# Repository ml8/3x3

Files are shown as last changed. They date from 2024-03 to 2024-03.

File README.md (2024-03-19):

# 3x3 Macropad: PCB, Firmware, STL, Programmer

Self-designed, hacked-together 3x3 macropad.

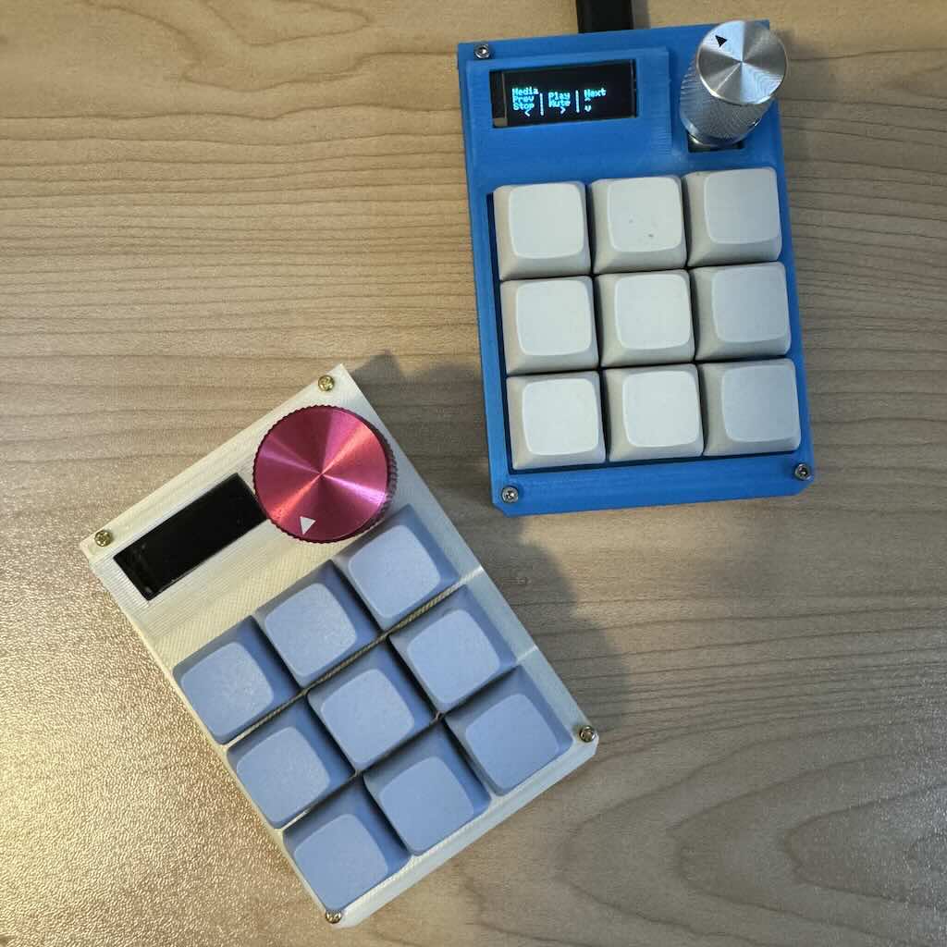
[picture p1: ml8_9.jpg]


## Features:

* 4 layers configurable with [via](https://www.caniusevia.com/) and selectable
  by clicking the rotary encoder.
* OLED display to display per-layer text (programmable with tool in
  [`cli/`](cli/README.md)).
* Rotary encoder with volume control and layer select button.
* 256Kb EEPROM (24LC256).

## Project layout:

* [`cli/`](cli/README.md) - Tool to program keyboard (primarily to change OLED
  text) and change the layer text.
* [`via/`](via/README.md) - Via json config (TODO: merge into via) that can be
  used for creating custom keymaps in Via (once merged into via, this should no
  longer be necessary).
* [`firmware/`](firmware/README.md) - [QMK](https://qmk.fm/)-based firmware
  (TODO: merge into QMK) and instructions for flashing the firmware.
* [`hardware/`](hardware/README.md) Gerber file for PCB and STL/3mf for
  enclosure.

## Updating firmware:

In order to flash a new firmware version, the device needs to be reset and
boot into DFU mode for flashing. This can be done in one of two ways:

* Hold down the top left key in the 3x3 grid and plug the keyboard in. The
  keyboard should enter DFU mode for a period of time that will allow you to
  flash new firmware.
* If this does not work, you can use the reset button on top of the PCB. You'll
  need to remove at least the top cover in order to access the button.

See the instructions in [`firmware/`](firmware/) for more details.

## Kit Assembly

Overview and detailed Assembly instructions can be found in the
[`hardware/`](hardware/README.md) directory.

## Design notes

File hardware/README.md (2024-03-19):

# Hardware

This contains the Gerber for the PCB and STL/3mf files for the enclosure.

## BOM

All components are through-hole except for the hot-swap sockets.

| Component | Quantity | Note |
| --- | --- | ---- |
| Arduino Pro Micro | 1 | |
| 0.91" 128x32 OLED | 1 | requires hand-wiring |
| 24LC256 EEPROM | 1 | | 
| 6x6 tactile momentary switch | 1 | 5mm or 4.3mm height |
| EC11 Rotary Encoder (clickable) | 1 | + knob |
| 1N4148 diodes | 10 | |
| MX-style switches | 10 | + keycaps |
| 1k resistor | 1 | |
| MX hotswap sockets | 10 | |
| m2x8 screws | 4 | for enclosure |
| m2x4 screws | 4 | for enclosure |
| m2 5mm standoffs | 4 | for enclosure |
| m2 nuts | 4 | for enclosure |

## Assembly Notes

The following is an overview of assembling the macropad. __You can find more
detailed instructions [here](./assembly_detailed.md).__

1. Begin by mounting 3x3 matrix diodes (D1-D9) and hotswap sockets to underside
   of board (where their labels are). Solder these in place.
   * The hotswap sockets are easiest to solder when you put a small amount of
     solder on the pad, then place the socket and heat the pad. 
   * The D10 diode will be soldered on top of the board. 
   * It's easier to solder the hotswap sockets first, so that you don't have to
     worry about the board sitting stably while soldering these.
2. Next, mount the D10 diode, the resistor (R-RESET) to top of board. Solder in
   place.
3. Mount the EEPROM, reset switch, and rotary encoder on top of the board; solder
   them in place.
4. Solder headers facing __upward__ on Pro Micro, then mount to bottom of
   PCB (see completed picture).
5. Use wires to connect sda/scl/vcc/gnd to the corresponding pins on the 128x32
   OLED. The OLED will be mounted to the inside of the enclosure, so make sure
   the wires are long enough to reach, but short enough to fit under the OLED
   once it is mounted.
6. Assemble the bottom of the enclosure, mounting the PCB to the standoffs.
    * Put the nuts in the bottom of the case (you may have to push hard to push
      them in--they should be snug).
    * Screw in the standoffs, then slide the PCB into the bottom of the
      enclosure.
    * Screw 4 m2x4 screws to mount the PCB inm place.
7. Put the switch plate on (do __not__ screw in place) and mount switches in
   hotswap sockets.
8. Program the firmware, if the pro micro is not pre-programmed. Follow the
   instructions in [`firmware/`](../firmware/README.md).
9. Tape or otherwise affix the OLED to the inside of the top of the enclosure,
   then mount the enclosure. Screw it in place with 4 m2x8 screws. Put the
   encoder knob on.

## Assembly Photos

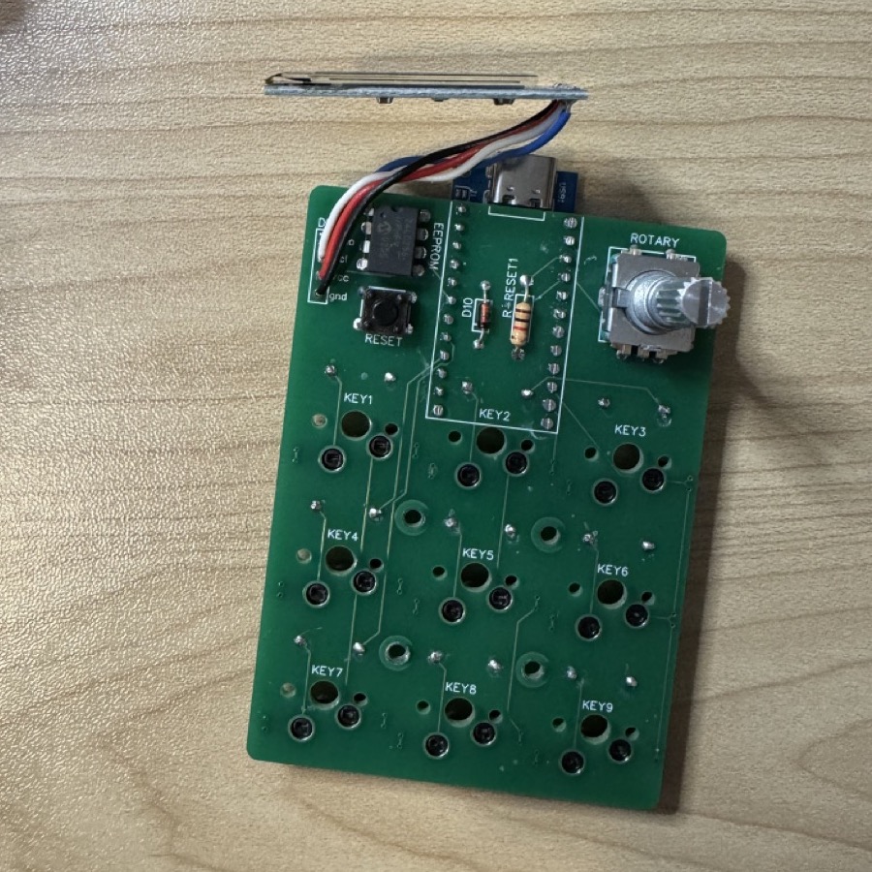
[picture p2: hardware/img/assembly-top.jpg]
top


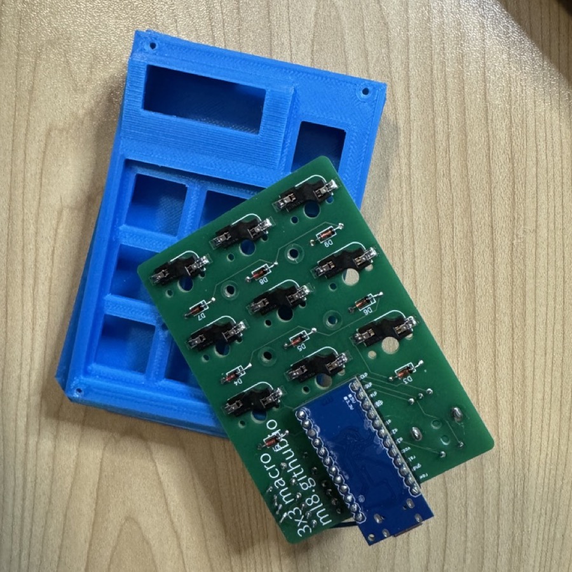
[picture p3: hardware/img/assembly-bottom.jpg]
bottom


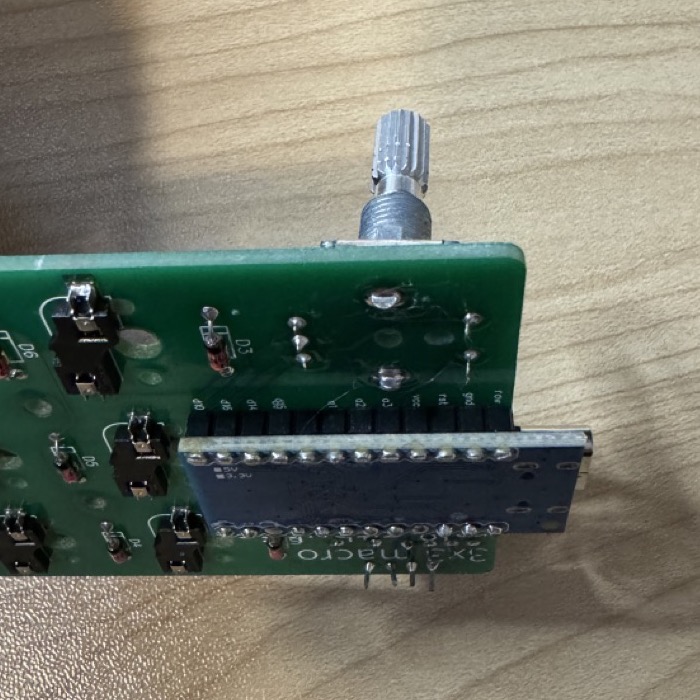
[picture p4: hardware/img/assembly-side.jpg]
side


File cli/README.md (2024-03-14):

# CLI programming tool

Requires golang to be installed.

The programming tool uses device id to distinguish between other QMK keyboards
that may be attached to the same machine. If you only have one QMK keyboard, you
can leave off the device string.

To program layer text:

```
$ go run ./cmd/kbp -device ::6d6c::: -layer [0-3] -text "TEXT"
```

You can use `\\n` for new lines. All text will be written to a single wrapped
line, otherwise.

To reset the layer text:

```
$ go run ./cmd/kbp -device ::6d6c::: -reset
```

Other commands (turning off the OLED, etc.) can be found by using the `-help`
flag.

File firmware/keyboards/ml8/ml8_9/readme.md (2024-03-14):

# ml8/ml8\_9

ml8/ml8\_9

*Firmware for 3x3 macropad with rotary encoder and OLED. Supports via and
reprogramming OLED text via hid programming.*

* Keyboard Maintainer: [Marion Lang](https://github.com/ml8)
* Hardware Supported: [ml8\_9](https://github.com/ml8/3x3)
* Hardware Availability: [open source](https://github.com/ml8/3x3)
* OLED display programmer: [repo](https://github.com/ml8/3x3)

Make example for this keyboard (after setting up your build environment):

    make ml8/ml8_9:default

Flashing example for this keyboard:

    make ml8/ml8_9:default:flash

See the [build environment setup](https://docs.qmk.fm/#/getting_started_build_tools) and the [make instructions](https://docs.qmk.fm/#/getting_started_make_guide) for more information. Brand new to QMK? Start with our [Complete Newbs Guide](https://docs.qmk.fm/#/newbs).

## Bootloader

Enter the bootloader in 3 ways:

* **Bootmagic reset**: Hold down the key at (0,0) in the matrix (top left key in 3x3 matrix) and plug in the keyboard
* **Physical reset button**: Briefly press the button on the top of the PCB
* **Keycode in layout**: Press the key mapped to `QK_BOOT` if it is available

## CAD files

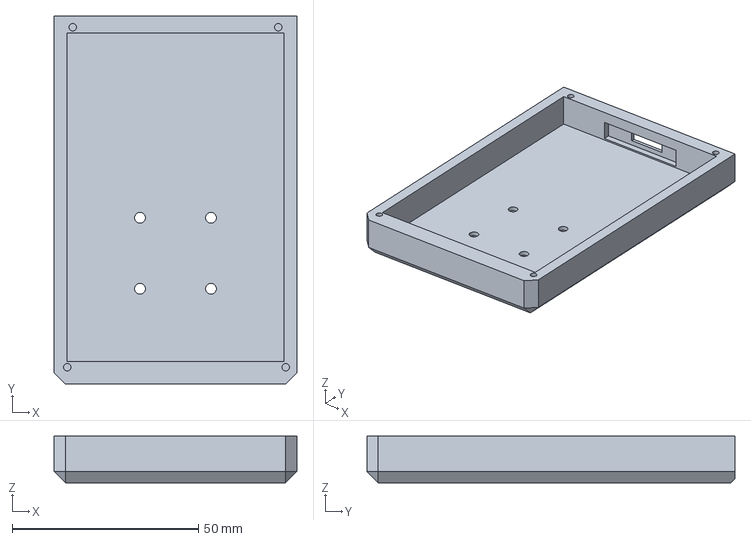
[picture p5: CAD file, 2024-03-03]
hardware/3mf/body.3mf
65.1 x 98.8 x 12.5 mm

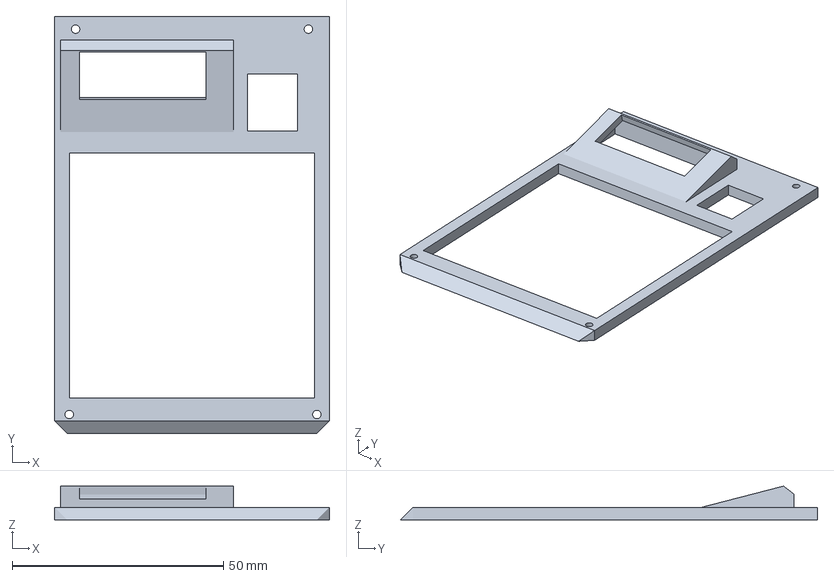
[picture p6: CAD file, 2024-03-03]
hardware/3mf/top.3mf
65.1 x 98.8 x 8.01 mm

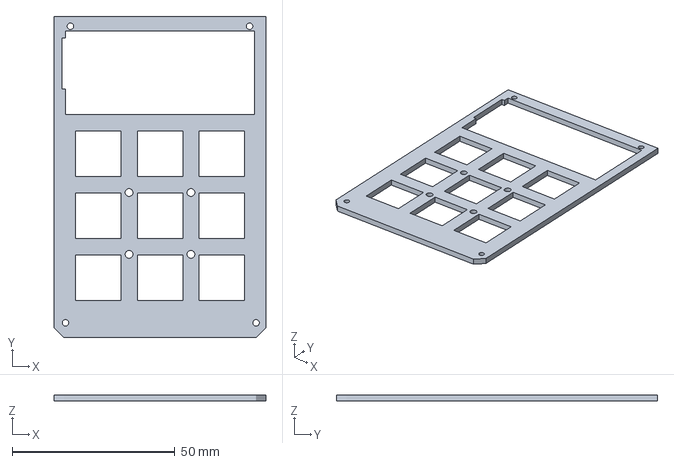
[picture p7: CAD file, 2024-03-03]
hardware/3mf/plate.3mf
65.1 x 98.8 x 2.00 mm

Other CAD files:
hardware/stl/body.stl
hardware/stl/plate.stl
hardware/stl/top.stl

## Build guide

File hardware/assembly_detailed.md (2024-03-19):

# Detailed Assembly Instructions

## Collect materials

Assembling the macropad is relatively straightforward if you have experience
soldering through-hole components. There are a small number of discrete
components. The photo below lays them out.

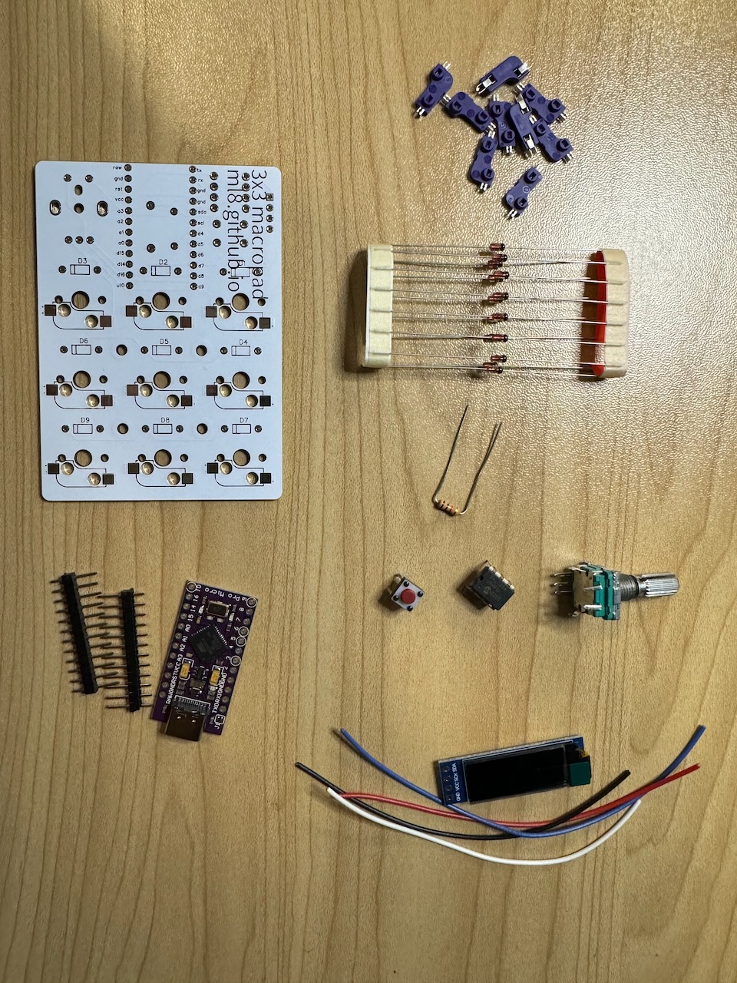
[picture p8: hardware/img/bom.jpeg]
materials


On the left, top to bottom:

* The PCB.
* An Arduino Pro Micro and headers.

On the right, top to bottom (conveniently arranged in the order they'll be
assembled):

* Hot swap switch sockets.
* 1N4148 diodes.
* A 1k ohm resistor.
* Reset/firmware flash button, 24LC256 EEPROM, and rotary encoder.
* 0.91" 128x32 OLED and wires for it.

The rest of these instructions are a suggested order for installing these
components. Note that there is one time when building that a fixed order is
required: __D10 and the resistor__ must be installed before the Arduino.

## Hot swap sockets

The hot swap sockets are the only component that may be unfamiliar to solder if
you are used to through-hole soldering.

Instead of trying to solder the socket tabs directly to the pads they mount on,
it is helpful to first put a blob of solder on the pad.

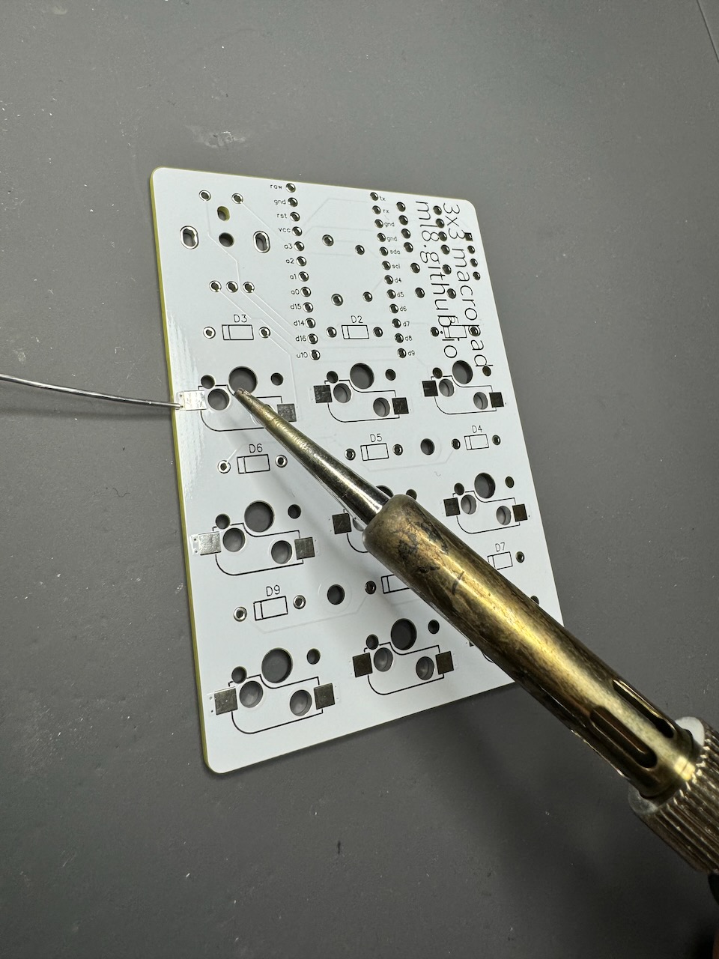
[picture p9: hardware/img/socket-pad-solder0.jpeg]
solder on pad


solder on pads

After putting a bit of solder on each pad, you can now install the sockets.

Pay attention to the orientation of the socket; if the socket is rotated
it will still fit in the holes in the PCB, but it will partially cover the hole
through which the switch stem will need to go.

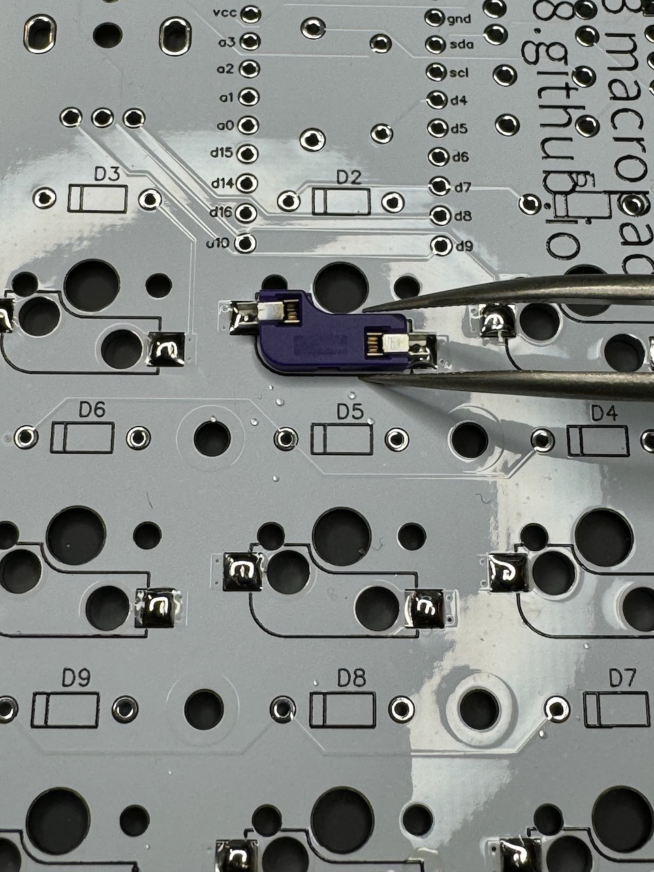
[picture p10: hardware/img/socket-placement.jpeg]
socket placement


To solder the socket to the PCB, place the socket in its location. Then apply
your soldering iron to the socket's tabs. This will melt the solder beneath the
pad after a few seconds and solder the tab to the pad.

You may want to use a pair of tweezers to hold the socket and the tab down while
applying heat.

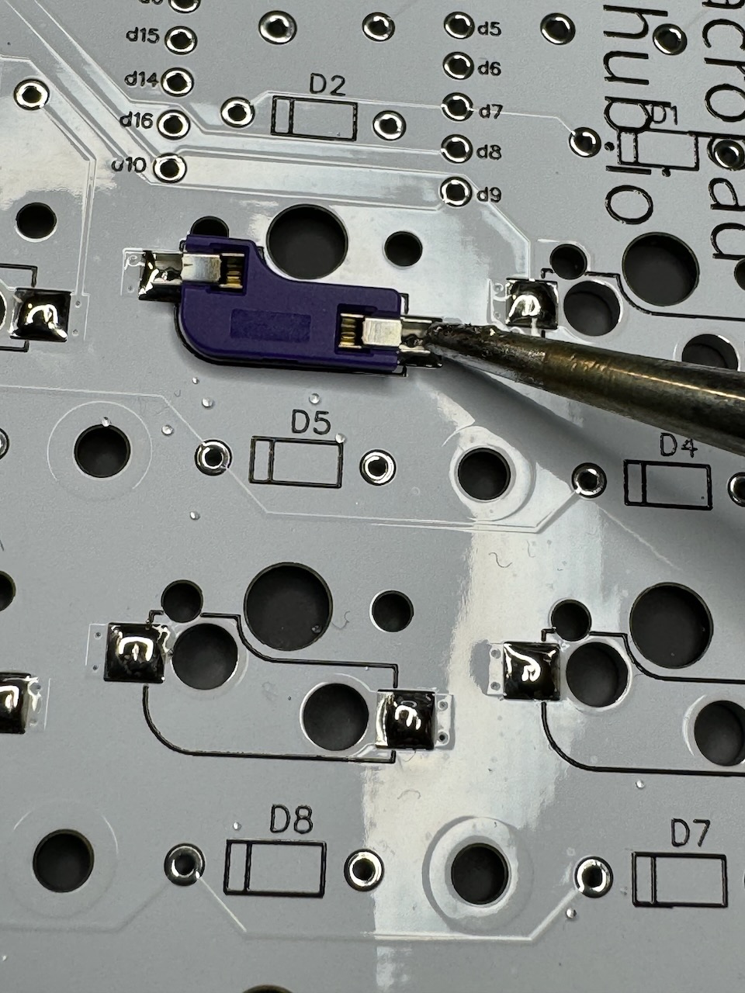
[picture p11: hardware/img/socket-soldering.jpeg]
socket soldering


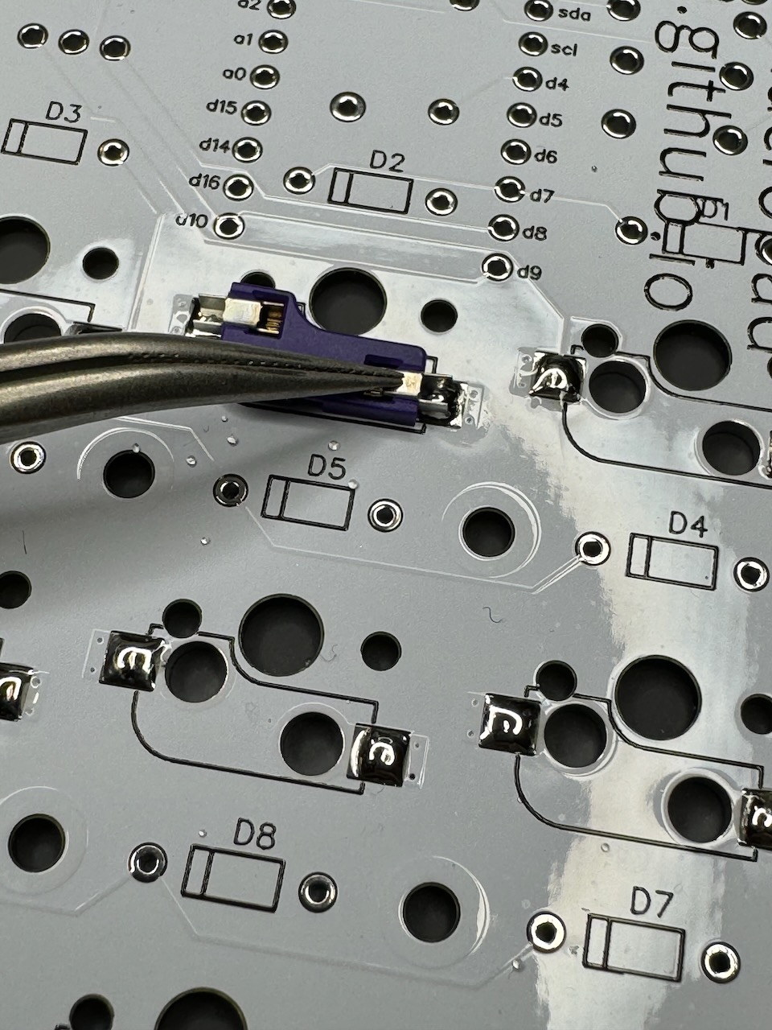
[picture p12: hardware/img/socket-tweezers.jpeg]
hold in place with tweezers


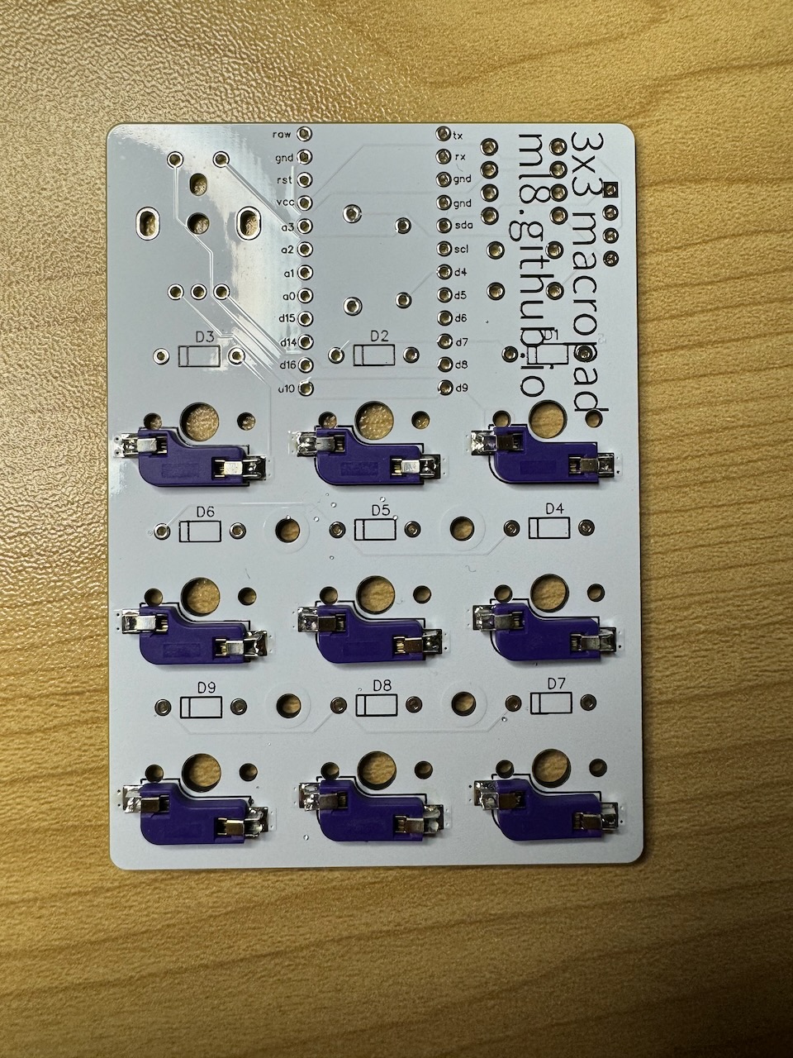
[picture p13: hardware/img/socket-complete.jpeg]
sockets completed


## Diodes 1-9

Now you'll install the diodes. To solder the diode, put the body of the diode on
the bottom of the PCB (the side with the sockets) and the legs through the holes
to the top of the board.

Pay attention to the orientation of the diode -- the orientation matters. The
footprint symbol on the PCB indicates the orientation.

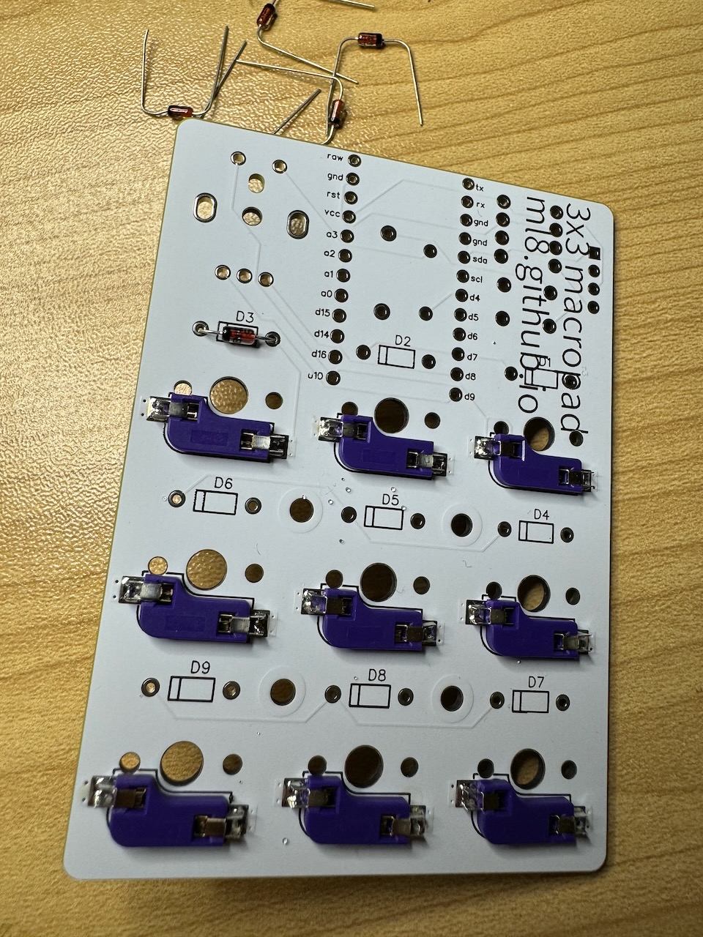
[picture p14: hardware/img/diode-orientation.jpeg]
diode orientation


After putting all the diodes in place, you'll end up with something like this.

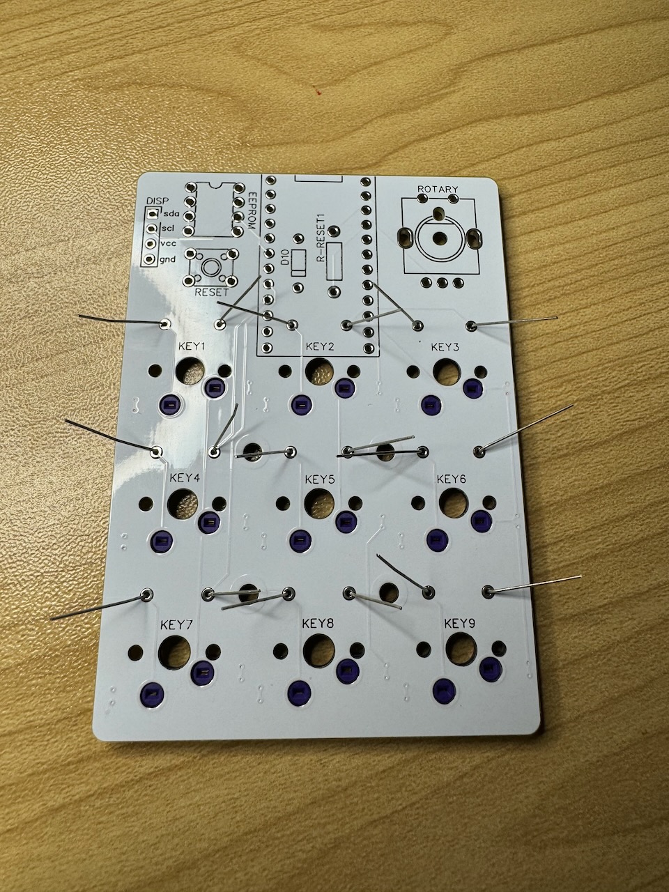
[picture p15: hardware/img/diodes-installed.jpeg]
diodes installed


Solder the legs in place. Cut off the legs when you're done. You should have
something that looks like this:

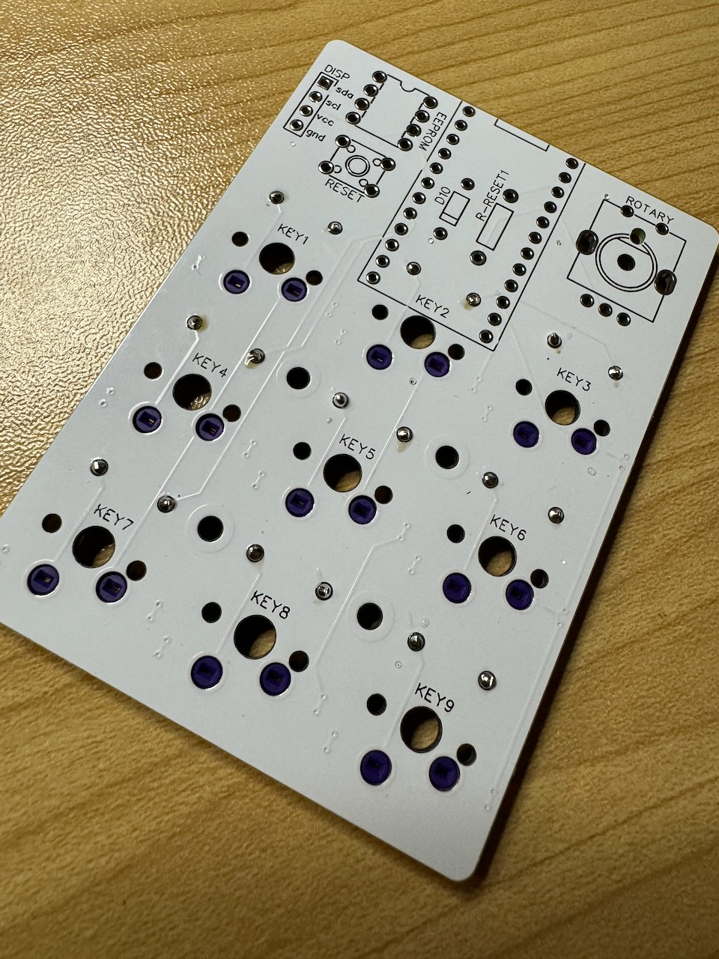
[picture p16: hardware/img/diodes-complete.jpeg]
diodes complete


## Diode 10 and resistor

Diode 10 and the resistor should be placed on top of the board. Their legs will
go through the board and should be soldered from the bottom.

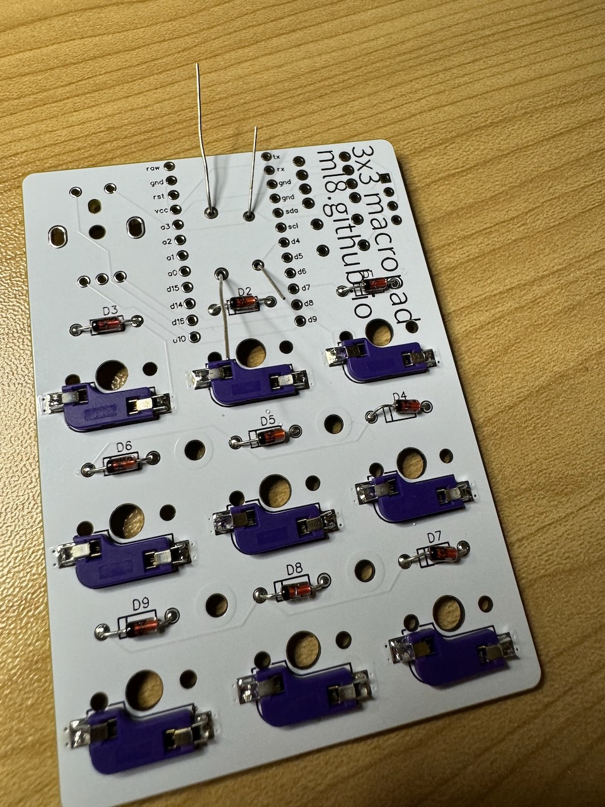
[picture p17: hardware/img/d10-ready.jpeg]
D10 and the resistor ready to solder


When you're complete, the top of the board should look like this.

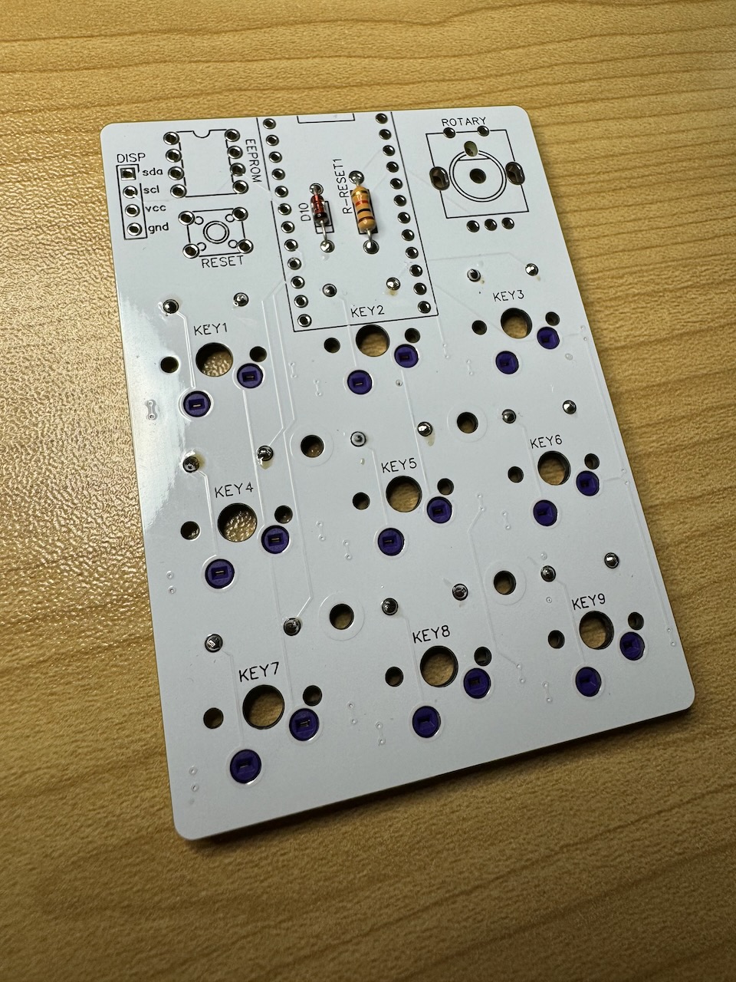
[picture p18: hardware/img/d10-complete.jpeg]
D10 and resistor installed


## EEPROM, reset button, and rotary encoder

Now you can install the EEPROM, reset button, and rotary encoder on the top of
the PCB. All of these components have fixed orientations. The button and the
rotary encoder can only be installed one way, so those should be self-evident.

The EEPROM has a semi-circular notch and dot that indicate the orientation of
the IC and pin 1. Line up the notch with the footprint diagram on the PCB (see
image below).

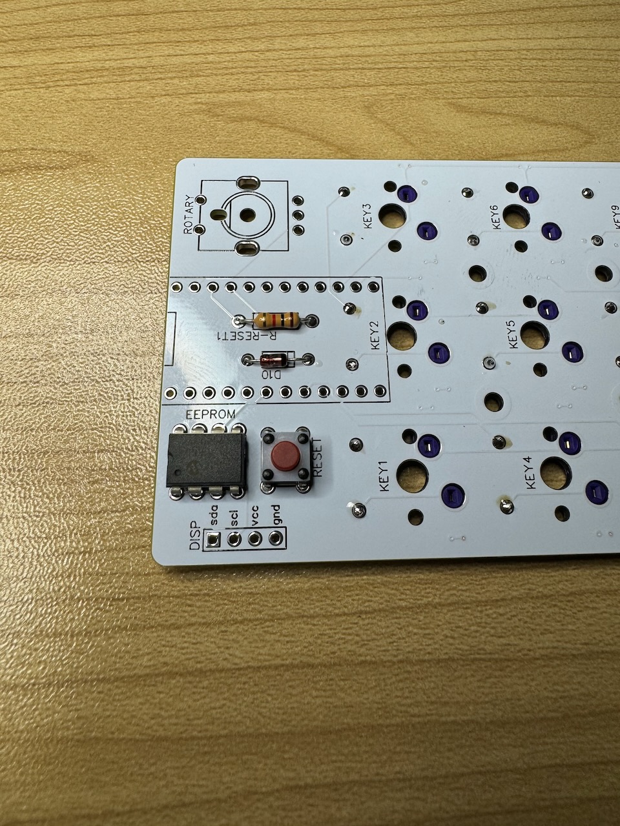
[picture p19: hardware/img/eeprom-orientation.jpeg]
EEPROM orientation


You'll solder each of these components from the bottom. You should install the
EEPROM and the button first, using painters tape or sticky tack to hold them in
place if necessary.

Install the rotary encoder last. Note that you should solder the large tabs on
the side of the encoder, even though they do not carry signal. Soldering these
to the PCB will add stability.

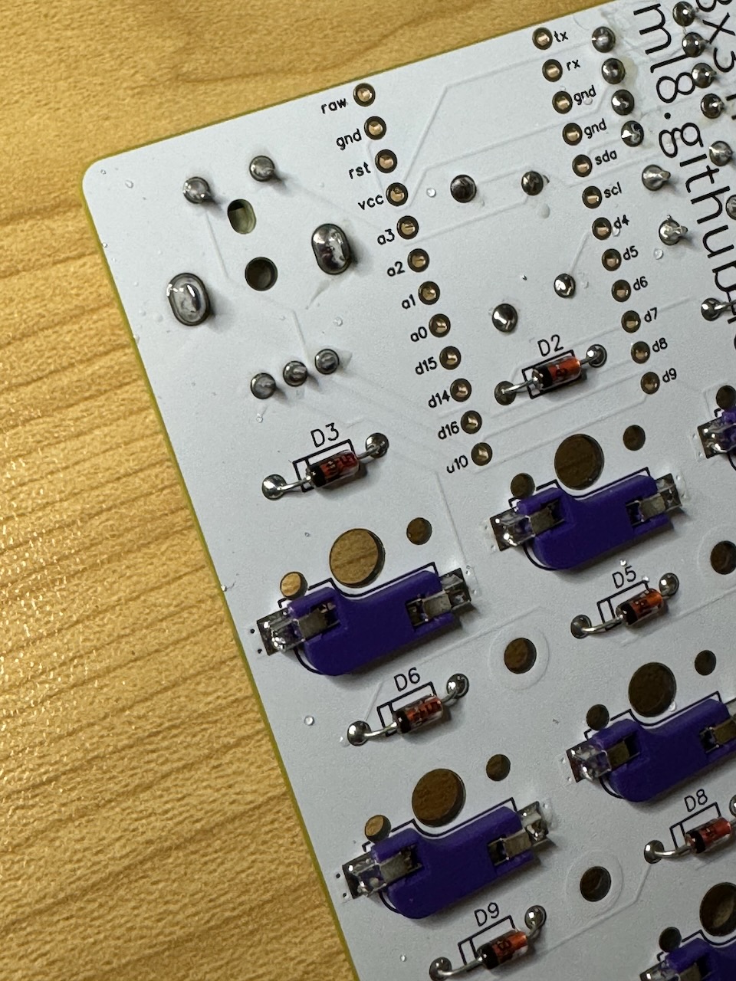
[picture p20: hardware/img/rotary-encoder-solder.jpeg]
rotary encoder tabs


It isn't necessary to trim the legs of any of these components, but it doesn't
hurt anything to do so.

## Arduino

Finally, you'll install the Arduino MCU dev board. This component is installed
kind of oddly (suspended from the bottom of the board). 

First, you'll want to solder the headers to the Ardunio. But __not__ how you
might solder these when using an Arduino on a breadboard. 

You'll want the finished product to look like this (note the long end of the
headers is facing up).

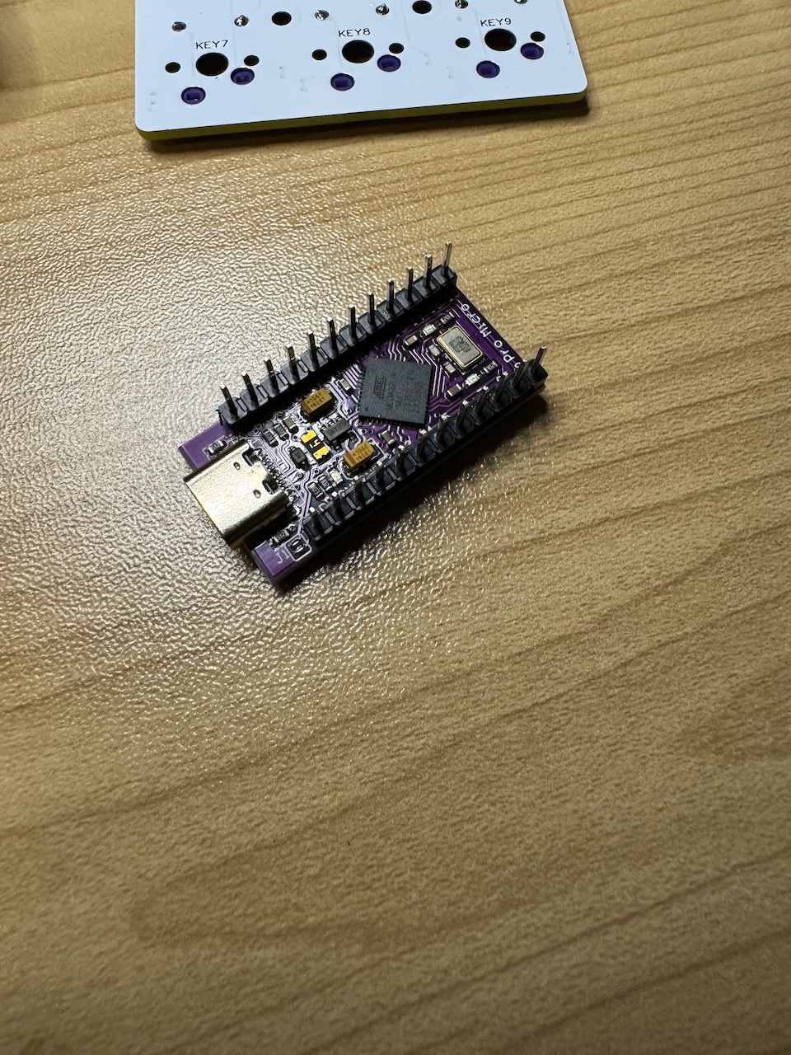
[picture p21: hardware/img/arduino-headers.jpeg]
arduino finished headers


You might find it helpful to do this upside down, with the headers sitting in
their location in the PCB (in order to ensure that they are
straight/perpendicular to both the macropad and the Arduino PCB).

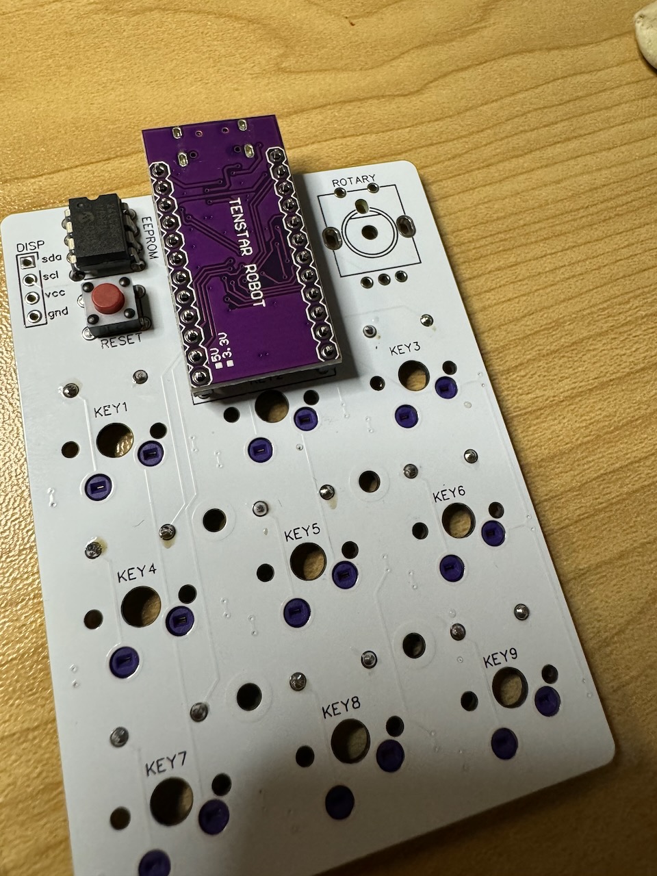
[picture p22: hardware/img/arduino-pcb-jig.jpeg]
arduino pcb as jig


When you are done soldering the headers to the Arduino, install the Arudino on
the bottom of the PCB and solder the headers to the top.

Note that you will need to closely trim the leads on the bottom of the Arduino
and will want to trim the excess header leads on the top of the PCB.

Your finished product should look like this.

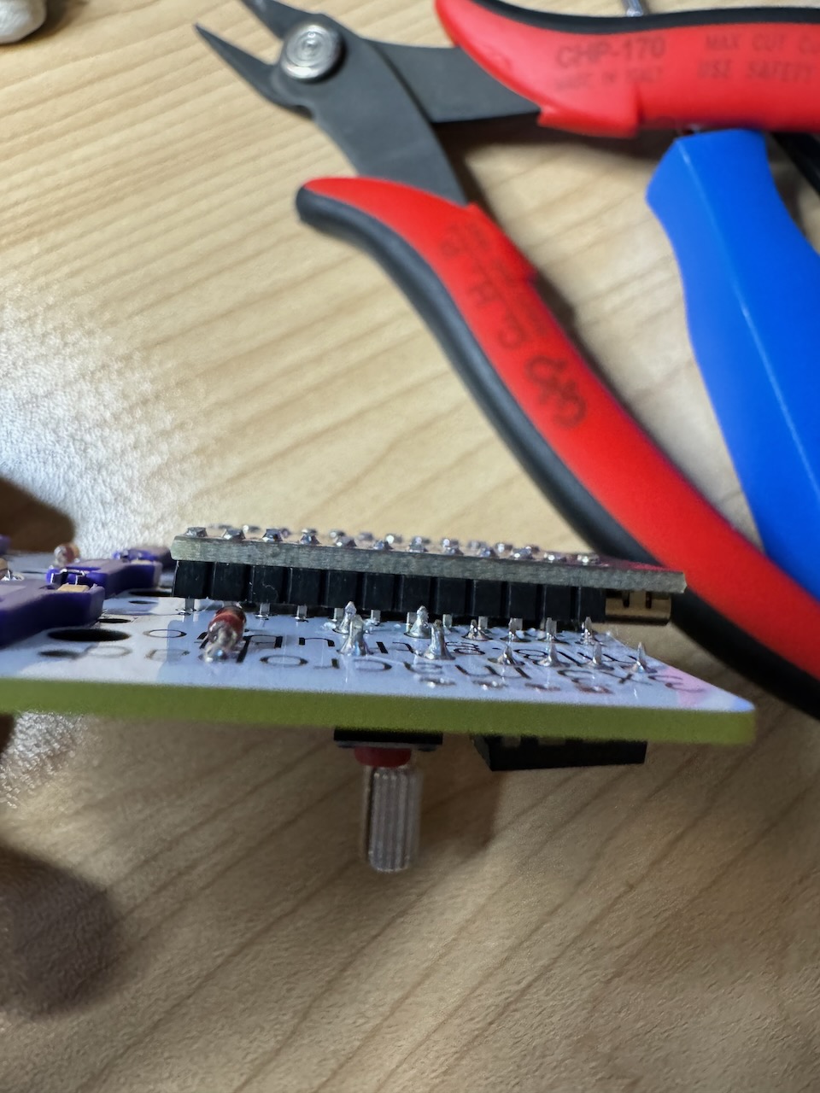
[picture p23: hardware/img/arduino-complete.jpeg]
arduino complete


## OLED

The last component you'll install is the OLED. This is the easiest component to
install, but can be finicky after installing, since you'll need to tape the OLED
to the top of the case. 

For this, you'll just need to solder VCC to VCC, Ground to Ground, and
Clock and Data to Clock and Data. 

Note that I unhelpfully made the orientation of the PCB different from the
orientation of the finished OLED.

You're aiming for this picture.

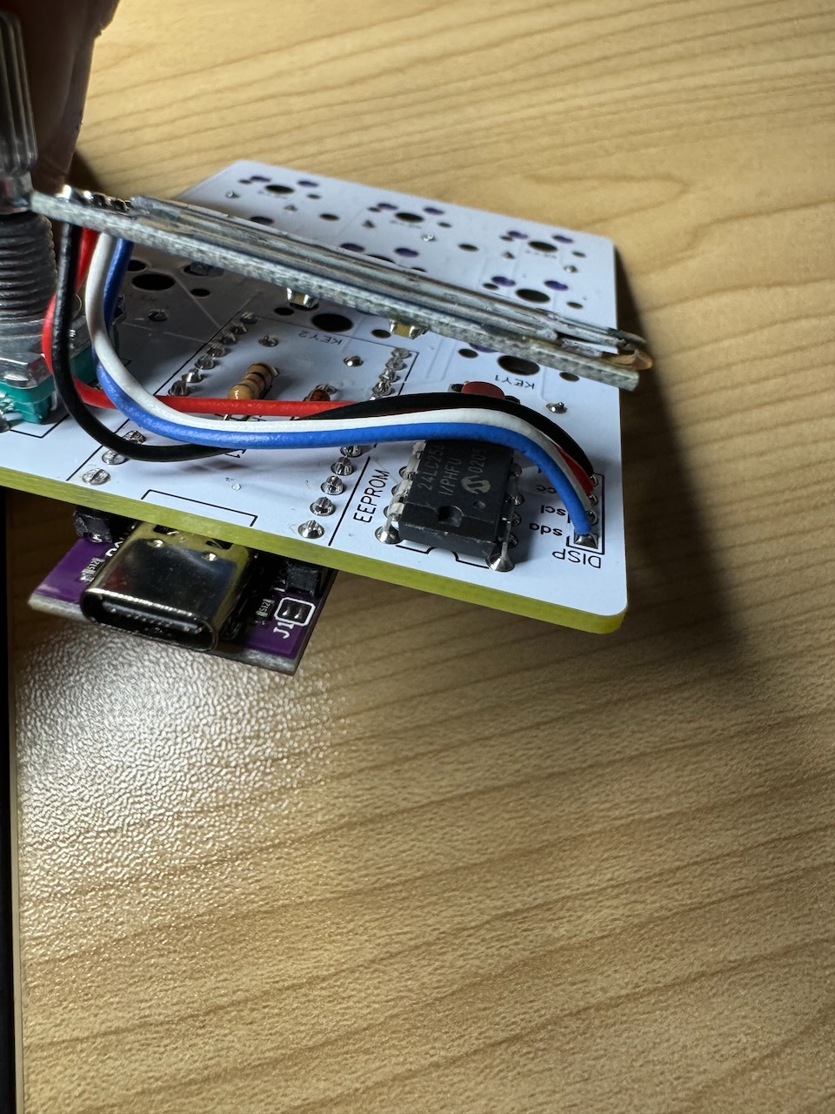
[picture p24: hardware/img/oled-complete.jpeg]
oled complete


## Assembling the case

Now, you'll assemble the case and install your completed PCB in the case.

You'll start by screwing the standoffs into the corresponding nuts. The nuts are
held in place by the cutouts on the bottom of the case. They may be a tight
squeeze. You can use the end of a screwdriver to push hard on the nuts to seat
them.

The PCB gets screwed into the standoffs. Once the PCB is seated, you can start
installing switches. Make sure that before you put the switches in, you put the
plate on the case. The plate is not screwed in until the final step, but you
should be able to use the switches to hold it in place.

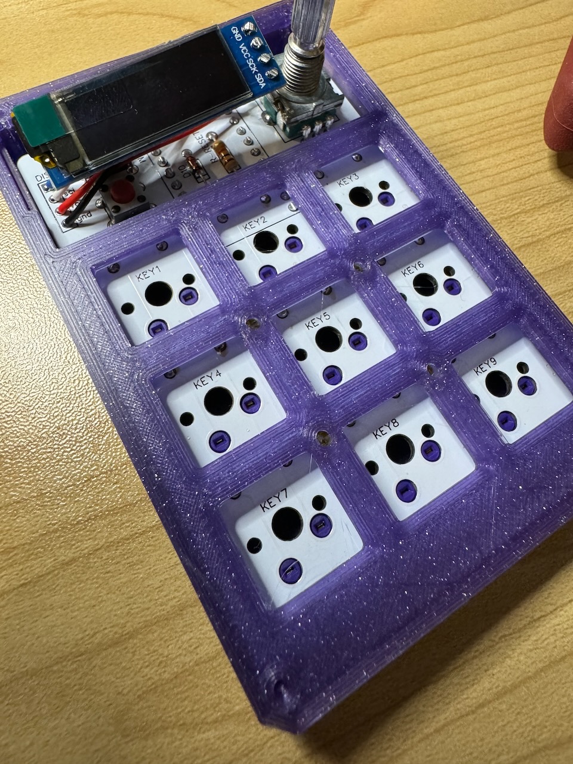
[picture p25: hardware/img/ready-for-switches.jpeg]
ready for switches


After you install the switches, put the top of the case on. Tape the OLED to the
inside of its viewport, then screw the top of the case into the plate and body.

Finally, put a knob on the rotary encoder.

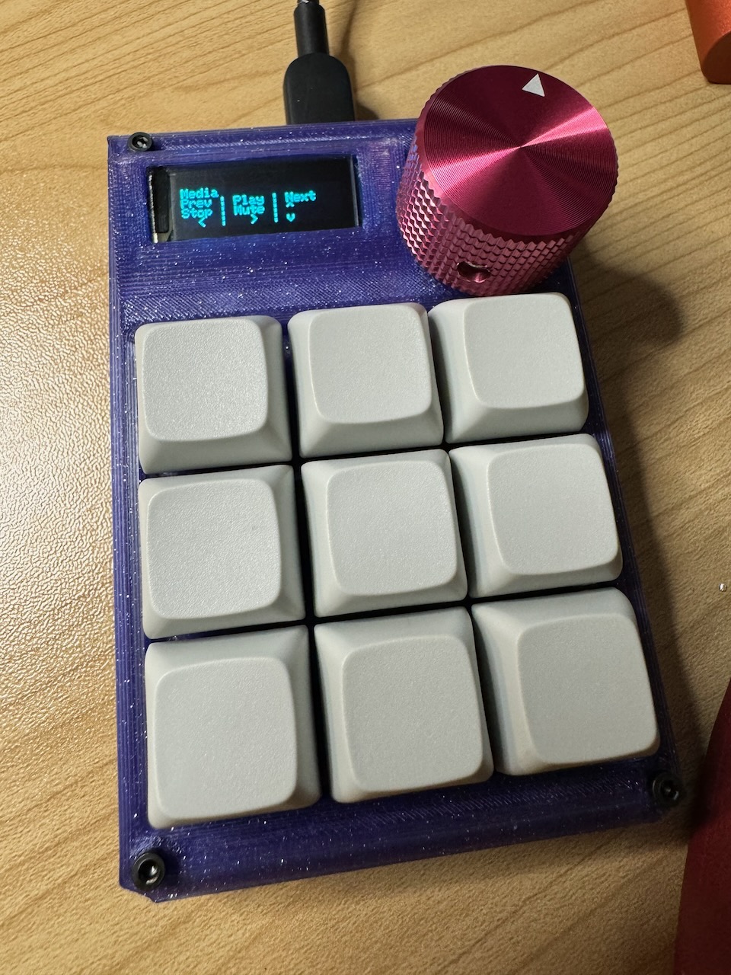
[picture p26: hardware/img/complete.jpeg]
all done


Congratulations, you're done! Now enjoy your macropad!

* Check out the [`firmware/`](../firmware) directory for information about how
  to flash new firmware (should you want/need to).
* Customize your layers with Via, using the json config and instructions in
  [`via/`](../via).
* Change the layer text with the programming tool in [`cli/`](../cli).

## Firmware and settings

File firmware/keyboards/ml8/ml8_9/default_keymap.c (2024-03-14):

#include "default_keymap.h"

#include "base.h"
#include "config.h"

#include <stdint.h>

#include QMK_KEYBOARD_H

#if defined(ENCODER_MAP_ENABLE)
const uint16_t PROGMEM encoder_map[][NUM_ENCODERS][2] = {[0] = {ENCODER_CCW_CW(KC_VOLU, KC_VOLD)}};
#endif

const uint16_t PROGMEM keymaps[][MATRIX_ROWS][MATRIX_COLS] = {
    // clang-format off
    [L_MEDIA] = LAYOUT_ortho_3x4(
        KC_MEDIA_PREV_TRACK, KC_MEDIA_PLAY_PAUSE, KC_MEDIA_NEXT_TRACK, 
        KC_MEDIA_STOP, KC_AUDIO_MUTE, KC_UP,
        KC_LEFT,       KC_RIGHT,      KC_DOWN, 
        KC_CYCLE_LAYERS, KC_NO,      KC_NO
    ),
    // For video calls:
    // push-to-talk  |  mute/unmute  |  video on/off
    // full screen   |  quit         |  confirm quit
    // raise/lower   |   x           |  x
    [L_ZOOM] = LAYOUT_ortho_3x4(
        KC_SPACE,   SGUI(KC_A), SGUI(KC_V), 
        SGUI(KC_F), LGUI(KC_W), KC_ENTER, 
        LOPT(KC_Y), KC_NO,      KC_NO, 
        KC_CYCLE_LAYERS,  KC_NO,      KC_NO
    ),
    [L_MEET] = LAYOUT_ortho_3x4(
        KC_SPACE,  LGUI(KC_D),  LGUI(KC_E), 
        LGUI(LCTL(KC_F)),  LGUI(KC_W),  KC_ENTER, 
        LGUI(LCTL(KC_H)),  KC_NO,  KC_NO, 
        KC_CYCLE_LAYERS, KC_NO, KC_NO
    ),
    [L_TEAMS] = LAYOUT_ortho_3x4(
        LOPT(KC_SPACE), SGUI(KC_M), SGUI(KC_O),
        LGUI(LCTL(KC_F)), SGUI(KC_H), KC_ENTER,
        SGUI(KC_K), KC_NO, KC_NO,
        KC_CYCLE_LAYERS, KC_NO, KC_NO
    )
    // clang-format on
};
